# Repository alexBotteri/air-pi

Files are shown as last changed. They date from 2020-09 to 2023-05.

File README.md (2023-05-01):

# AIR-PI README
Air-Pi is a DIY project to monitor the Air Quality. It uses the Raspberry pi, a particule matter sensor, a gas/temperature/humidity/pressure sensor and a and small display. The case is 3d printed. The total cost of all components is < $100. 

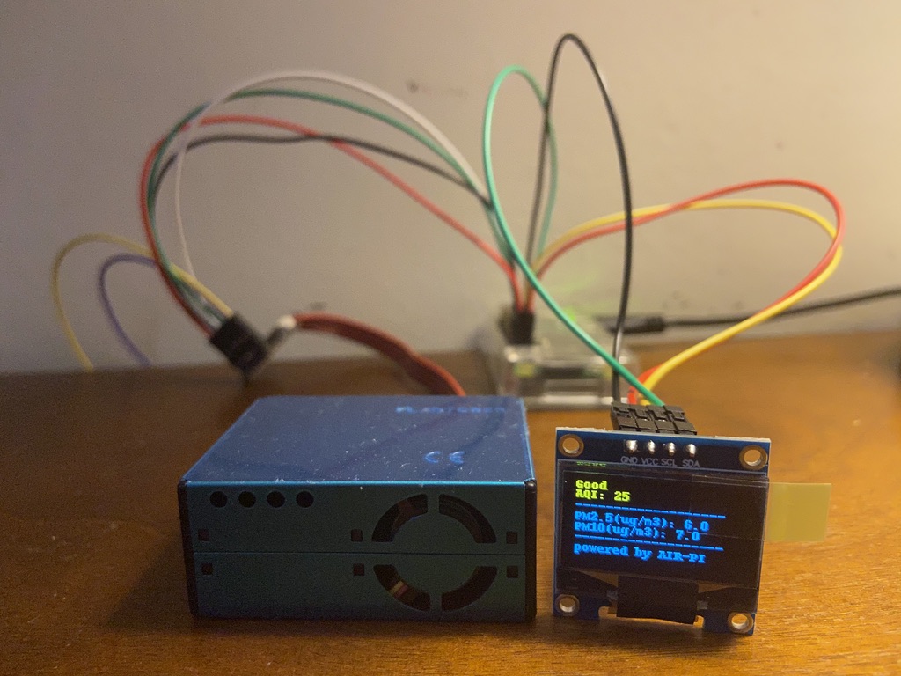
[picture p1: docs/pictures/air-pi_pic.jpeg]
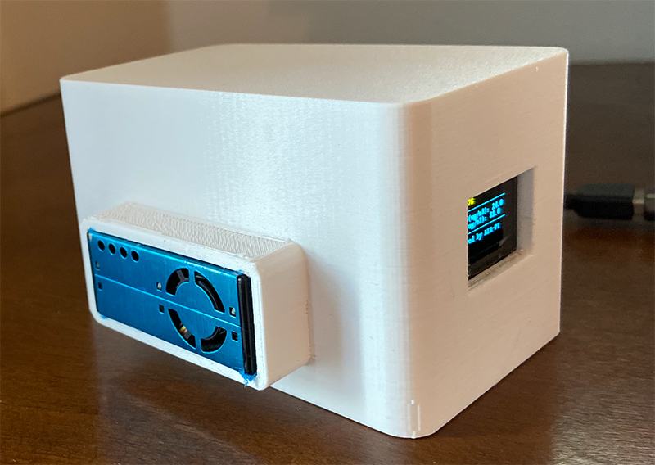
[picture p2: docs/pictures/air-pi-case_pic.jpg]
  

(The picture does not include the Gas sensor BME680, which was added later)

## Hardware

### Raspberry pi:

Raspberry pi Zero W
https://www.raspberrypi.org/products/raspberry-pi-zero-w/

### Sensor for Particule Matter:

- Particle Matter Sensor: Plantower PMS5003
http://www.plantower.com/en/content/?108.html

- UART breakout: by Pimoroni
https://shop.pimoroni.com/products/particulate-matter-sensor-breakout
(converts between the picoblade connector cable on the PMS5003 particulate matter sensor and a standard male 2.54mm pitch header)

### Sensor for Gas, Temperature, Humidity, Pressure:
- bme680:
https://www.digikey.com/en/products/detail/pimoroni-ltd/PIM357/9356663?so=80005127&content=productdetail_US

### Display:

- UCTRONICS 0.96 Inch OLED Module 12864 128x64 Yellow Blue SSD1306 - Driver I2C Serial
https://www.uctronics.com/index.php/uctronics-0-96-inch-oled-module-12864-128x64-yellow-blue-ssd1306-driver-i2c-serial-self-luminous-display-board-for-arduino-raspbe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

### Case - 3d print:
The case was designed using Sketchup. It is divided into 2 parts, the .stl are provided [here](https://github.com/alexBotteri/air-pi/tree/master/case-3d).

### RaspeberryPi IOs
Both the screen and the bme680 are using the i2c bus, one option is to create a 2nd bus so that they do not have to share the same PINs and we do not to have to worry about potiential issues with addresses overlap if using the same bus:

add the line in /boot/config.txt:
> dtoverlay=i2c-gpio,bus=4,i2c_gpio_delay_us=1,i2c_gpio_sda=23,i2c_gpio_scl=24

## Software

-- tested with Python 3.7 --

### Install dependencies
> pip3 install -r requirements.txt

### Launch
> python3.7 air-pi.py

Launch in background :
> nohup python air-pi.py &

### Launch at Boot (with a Cron job)
> crontab -e

add to the file:
> @reboot /usr/bin/python3.7 [directory]/air-pi.py

### Credits

- Code for the Sensor Controller:
https://github.com/dobra-dobra/Python_PMS5003

- Code for the Display Controller:
https://circuitdigest.com/microcontroller-projects/ssd1306-oled-display-with-raspberry-pi

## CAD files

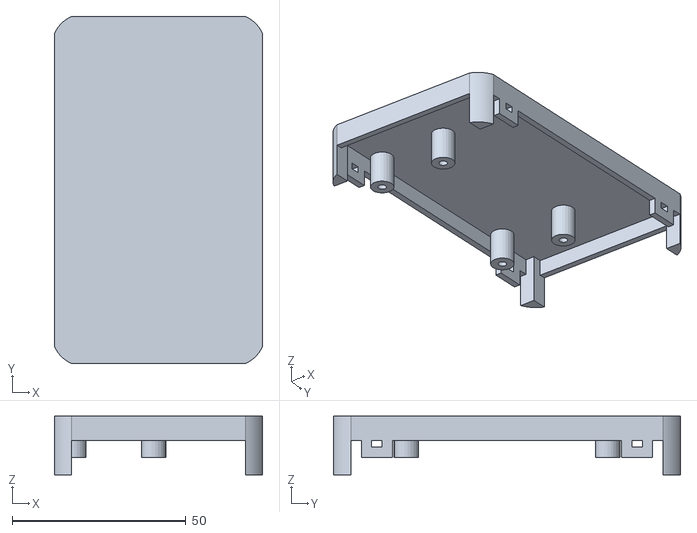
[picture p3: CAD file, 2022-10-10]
case-3d/airpi-box-bottom.stl
60.0 x 100.0 x 17.0

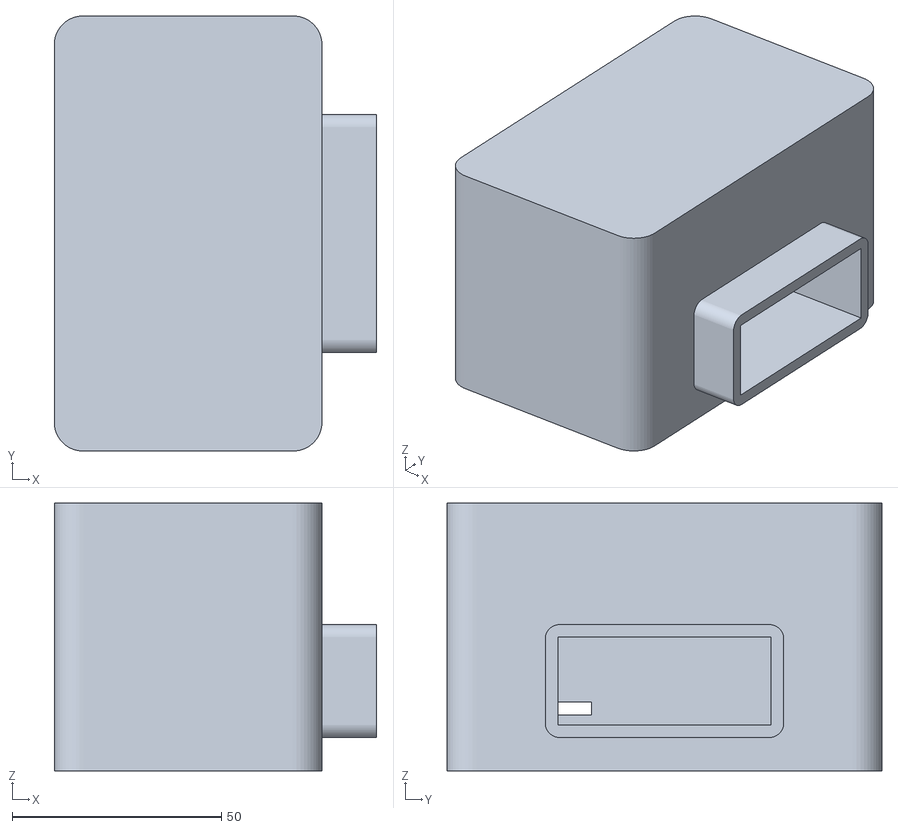
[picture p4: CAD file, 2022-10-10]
case-3d/airpi-box-top.stl
77.1 x 104.0 x 64.0

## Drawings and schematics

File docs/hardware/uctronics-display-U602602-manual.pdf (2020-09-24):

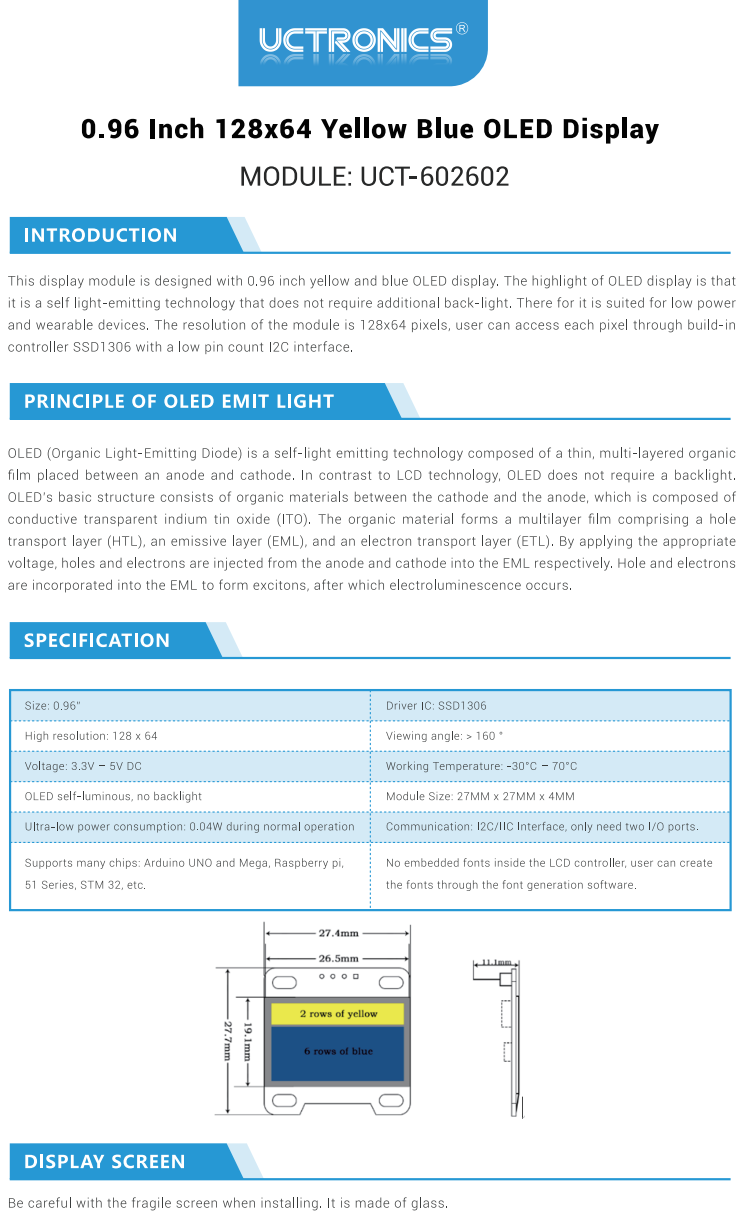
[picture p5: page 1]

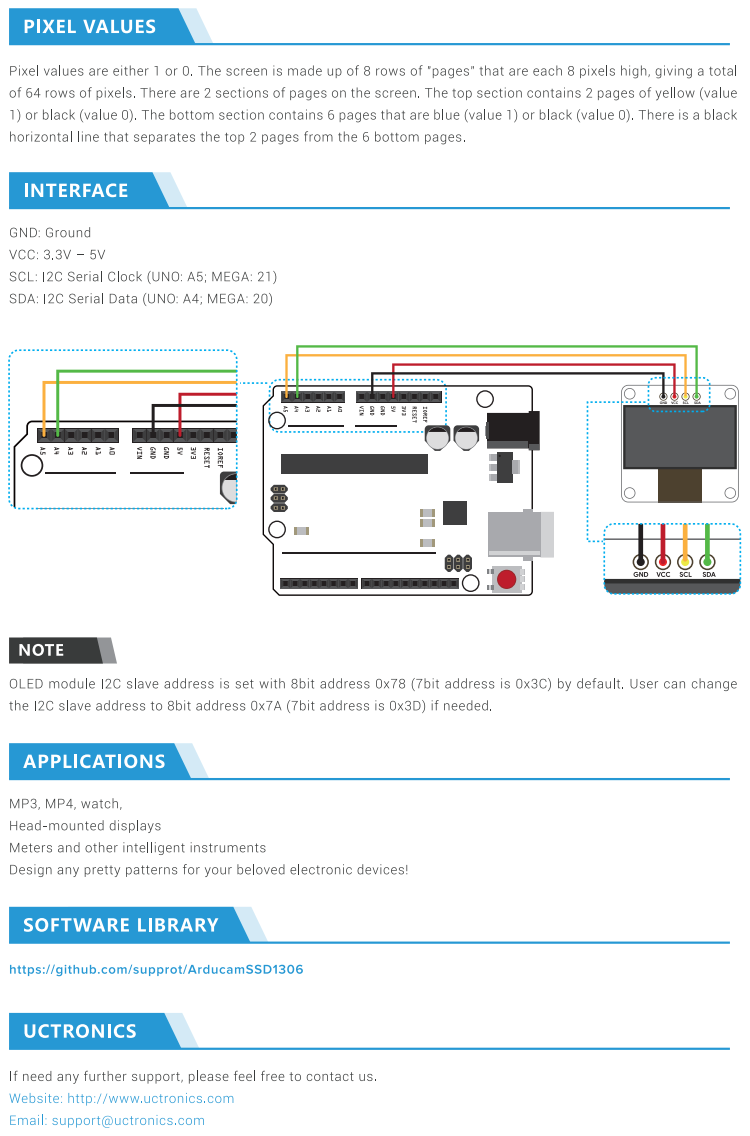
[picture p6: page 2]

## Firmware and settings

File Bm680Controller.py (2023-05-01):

#!/usr/bin/env python

import bme680
import time
import smbus
import bme680AqiTracker

class Bm680Controller:
    temperature = 0
    pressure = 0
    humidity = 0
    gasAqi= 0

    # see https://github.com/pimoroni/bme680-python
    sensor: bme680.BME680 = None
    
    # see https://github.com/thstielow/raspi-bme680-iaq
    aqiTracker: bme680AqiTracker.IAQTracker = None

    def __init__(self):
        try:
            self.sensor = bme680.BME680(bme680.I2C_ADDR_PRIMARY, smbus.SMBus(4))
        except (RuntimeError, IOError):
            self.sensor = bme680.BME680(bme680.I2C_ADDR_SECONDARY)
        
        # These calibration data can safely be commented
        # out, if desired.
        
        print('Calibration data:')
        for name in dir(self.sensor.calibration_data):
             
            if not name.startswith('_'):
                value = getattr(self.sensor.calibration_data, name)
                
                if isinstance(value, int):
                    print('{}: {}'.format(name, value))
        
        # These oversampling settings can be tweaked to
        # change the balance between accuracy and noise in
        # the data.
        
        self.sensor.set_humidity_oversample(bme680.OS_2X)
        self.sensor.set_pressure_oversample(bme680.OS_4X)
        self.sensor.set_temperature_oversample(bme680.OS_8X)
        self.sensor.set_filter(bme680.FILTER_SIZE_3)
        self.sensor.set_gas_status(bme680.ENABLE_GAS_MEAS)
        
        print('\n\nInitial reading:')
        for name in dir(self.sensor.data):
            value = getattr(self.sensor.data, name)
            
            if not name.startswith('_'):
                print('{}: {}'.format(name, value))
        
        self.sensor.set_gas_heater_temperature(320)
        self.sensor.set_gas_heater_duration(150)
        self.sensor.select_gas_heater_profile(0)
        
        # Up to 10 heater profiles can be configured, each
        # with their own temperature and duration.
        # sensor.set_gas_heater_profile(200, 150, nb_profile=1)
        # sensor.select_gas_heater_profile(1)
        
        self.aqiTracker = bme680AqiTracker.IAQTracker()

    def read(self):
        try:
            print('\n\nBME680 reading:')
            if self.sensor.get_sensor_data():
                output = '{0:.2f} C,{1:.2f} hPa,{2:.2f} %RH'.format(
                    self.sensor.data.temperature,
                    self.sensor.data.pressure,
                    self.sensor.data.humidity)
                
                self.temperature = self.sensor.data.temperature
                self.pressure = self.sensor.data.pressure
                self.humidity = self.sensor.data.humidity
                
                if self.sensor.data.heat_stable:
                    print('{0},{1} Ohms'.format(
                        output,
                        self.sensor.data.gas_resistance))
                    
                    try: 
                        #self.gasAqi = math.log(self.sensor.gas_resistance) + 0.04 * self.humidity 
                        self.gasAqi = self.aqiTracker.getIAQ(self.sensor.data)
                        print("{0:.1f}%aq".format(self.gasAqi))
                    except Exception as ex:
                        print(ex)
                        print("Gas sensor calibtrating, please wait")
                else:
                    print(output)
        except Exception as ex: 
            print('error reading bm680 data')
            print(ex)
        print('------------------\n\n')

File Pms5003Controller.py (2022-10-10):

import serial
import datetime
from time import sleep

def configSerialPort():
    # Specify serial port address
    ser_port = "/dev/ttyS0"
    ser = serial.Serial(ser_port, baudrate=9600, stopbits=1, parity="N",  timeout=2)
    return ser

def setPMSSensorInPassiveMode(ser):
    ser.write([66, 77, 225, 0, 0, 1, 112])   # put sensor in passive mode

def byteToUni(byte):
    return ord(chr(byte))

def readDataFromPMSSensor(ser):
    try:
        ser.flushInput()
        ser.write([66, 77, 226, 0, 0, 1, 113])   # ask for data
        s = ser.read(32)
        print(datetime.datetime.now())
        # Check if data header is correct
        if byteToUni(s[0]) == int("42",16) and byteToUni(s[1])== int("4d",16):
            cs = byteToUni(s[30]) * 256 + byteToUni(s[31])   # check sum
            # Calculate check sum value
            check = 0
            for i in range(30):
                check += byteToUni(s[i])
            # Check if check sum is correct
            if check == cs:
                # PM1, PM2.5 and PM10 values for standard particle in ug/m^3
                pm1_hb_std = byteToUni(s[4])
                pm1_lb_std = byteToUni(s[5])
                pm1_std = float(pm1_hb_std * 256 + pm1_lb_std)
                pm25_hb_std = byteToUni(s[6])
                pm25_lb_std = byteToUni(s[7])
                pm25_std = float(pm25_hb_std * 256 + pm25_lb_std)
                pm10_hb_std = byteToUni(s[8])
                pm10_lb_std = byteToUni(s[9])
                pm10_std = float(pm10_hb_std * 256 + pm10_lb_std)

                # PM1, PM2.5 and PM10 values for atmospheric conditions in ug/m^3
                pm1_hb_atm = byteToUni(s[10])
                pm1_lb_atm = byteToUni(s[11])
                pm1_atm = float(pm1_hb_atm * 256 + pm1_lb_atm)
                pm25_hb_atm = byteToUni(s[12])
                pm25_lb_atm = byteToUni(s[13])
                pm25_atm = float(pm25_hb_atm * 256 + pm25_lb_atm)
                pm10_hb_atm = byteToUni(s[14])
                pm10_lb_atm = byteToUni(s[15])
                pm10_atm = float(pm10_hb_atm * 256 + pm10_lb_atm)

                # Number of particles bigger than 0.3 um, 0.5 um, etc. in #/cm^3
                part_03_hb = byteToUni(s[16])
                part_03_lb = byteToUni(s[17])
                part_03 = int(part_03_hb * 256 + part_03_lb)
                part_05_hb = byteToUni(s[18])
                part_05_lb = byteToUni(s[19])
                part_05 = int(part_05_hb * 256 + part_05_lb)
                part_1_hb = byteToUni(s[20])
                part_1_lb = byteToUni(s[21])
                part_1 = int(part_1_hb * 256 + part_1_lb)
                part_25_hb = byteToUni(s[22])
                part_25_lb = byteToUni(s[23])
                part_25 = int(part_25_hb * 256 + part_25_lb)
                part_5_hb = byteToUni(s[24])
                part_5_lb = byteToUni(s[25])
                part_5 = int(part_5_hb * 256 + part_5_lb)
                part_10_hb = byteToUni(s[26])
                part_10_lb = byteToUni(s[27])
                part_10 = int(part_10_hb * 256 + part_10_lb)
                return {
                    'pm1': str(pm1_std), 'pm25': str(pm25_std), 'pm10': str(pm10_std),
                    'part03': str(part_03), 'part05': str(part_05), 'part1': str(part_1), 'part25': str(part_25),
                    'part5': str(part_5), 'part10': str(part_10)}
    except KeyboardInterrupt:
        ser.close()
        print("Serial port closed")
        return {}

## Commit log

2020-09-24 fixed crash when index out of range; added display of pm25, pm10 concentration data
    [Display1306Controller.py, Pms5003Controller.py, air-pi.py]
2020-09-28 first commit, basic read and print in console of the PMS5003 air quality data
2020-10-07 bug fix: the EPA concern mapping was returning the wrong value againt the aqi score
    [air-pi.py]
2020-11-05 case 3d .stl model - deisgned via sketchup
    [airpi-box-bottom.stl, airpi-box-top.stl]
2020-11-05 picture of 3d printed case added
2023-03-18 added BM680 for temperature, humidity, pressure and gas aqi
2023-05-01 added bme680 sensor for gas aqi, temperature, pressure and humidity
